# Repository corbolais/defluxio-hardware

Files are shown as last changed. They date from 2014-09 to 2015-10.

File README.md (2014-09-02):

Hardware for the netzsinus project
===================================

This repository contains the measurement hardware and firmware of the
netzsinus project. The current hardware is still under development -
you have to solder your own hardware. The hardware is, however, pretty
simple and easy to build.

Our vision is to develop a network analyzer in the sense of [DIN EN
50160](https://de.wikipedia.org/wiki/EN_50160). Currently, only the
network frequency is measured, but other measurements such as voltage
and harmonics will be included step-by-step.

Overview
--------

The hardware consists of

* A 9VAC wall-wart power adaptor. I have only tested Ideal Power model
DE-06-09, but others should also work.
* A STM32F4 Discovery board. This evaluation kit offers a Cortex M4
microcontroller which will become handy if we implement the harmonics
analysis.
* An adapter board which contains the analog frondend and connects all
the components.
* A raspberry pi which runs a simple Go daemon to read the data from the
hardware and transmit it to https://netzsin.us.

The current design powers the STM32F4 from the Raspberry Pi. It would also 
be possible to power the system from the 9VAC power adaptor, but initial 
experiments showed distorsions in the sine wave caused by the bridge rectifier.
A precision bridge rectifier setup could solve this.

Building your own device
------------------------

Currently, you just have to solder your own hardware. But since the
hardware is pretty simple this is an easy task. Please use this
schematic:

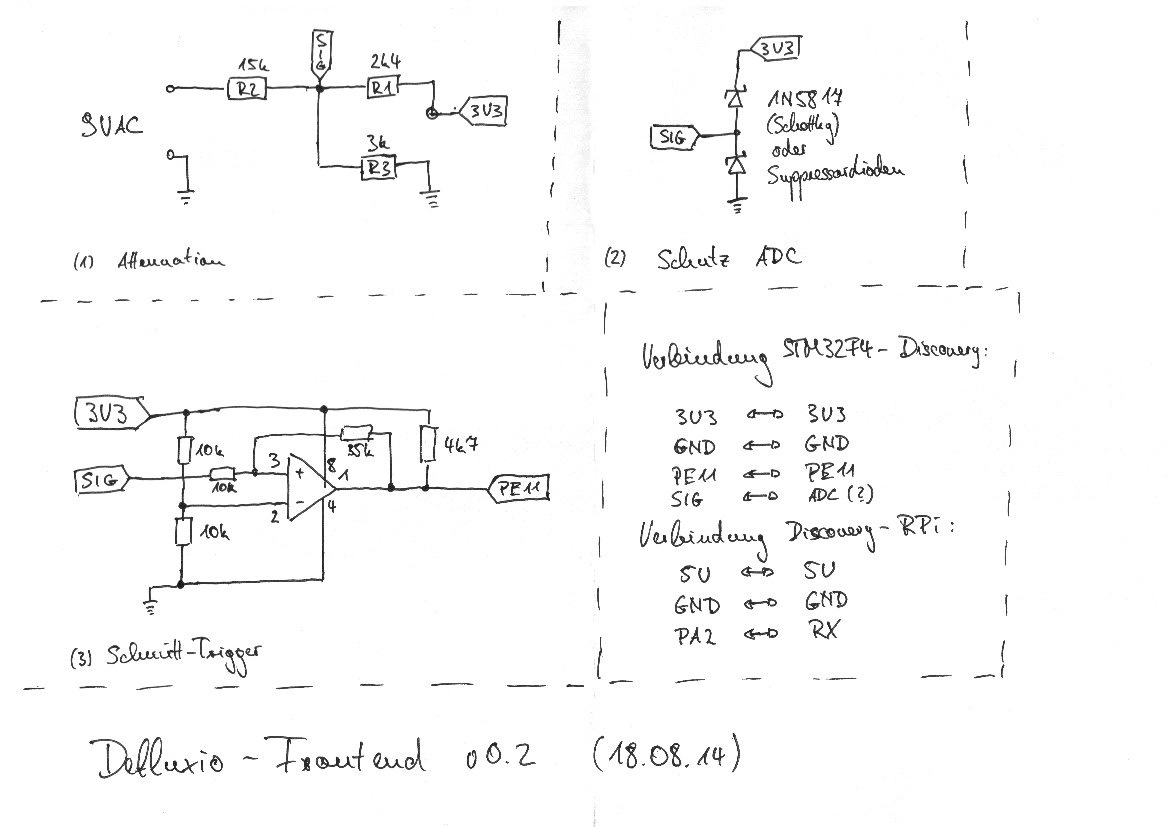
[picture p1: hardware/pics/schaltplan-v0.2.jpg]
Schematic


The opamp is an TLC393 comparator. I used a protoboard and THT components to build this circuit as a shield
for the STM32F4 discovery board. This is my setup:

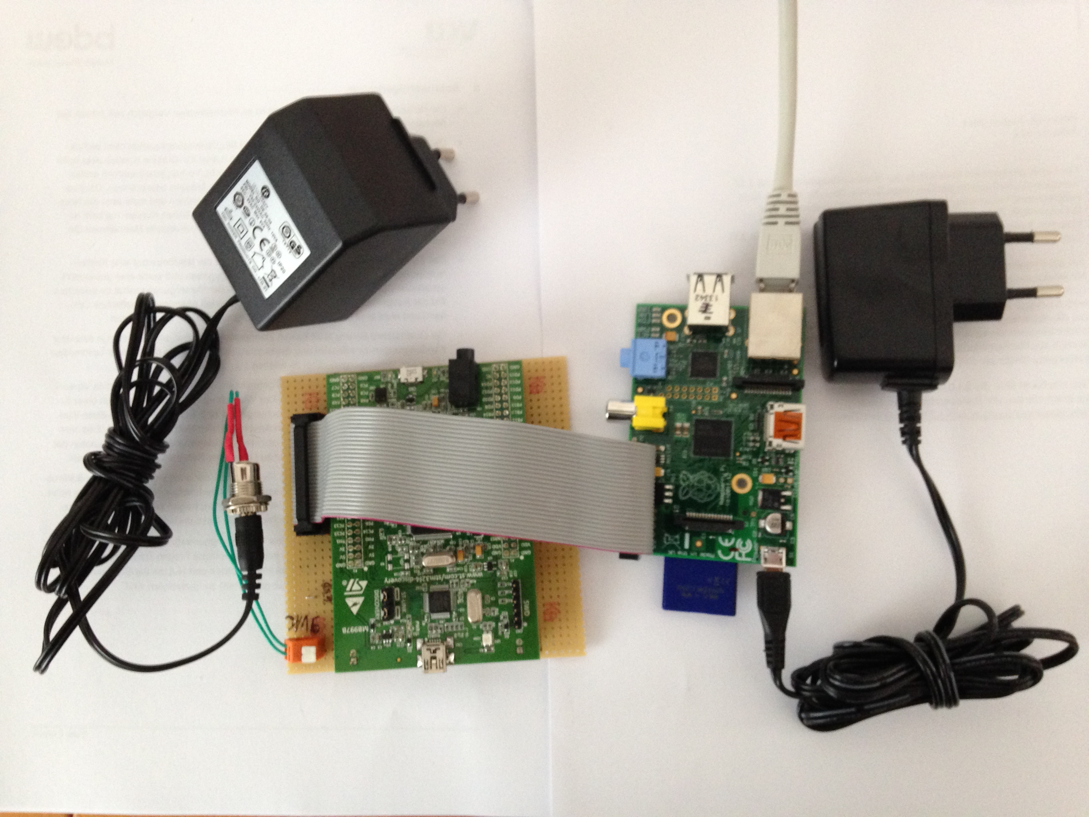
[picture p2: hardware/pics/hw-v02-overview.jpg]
Overview


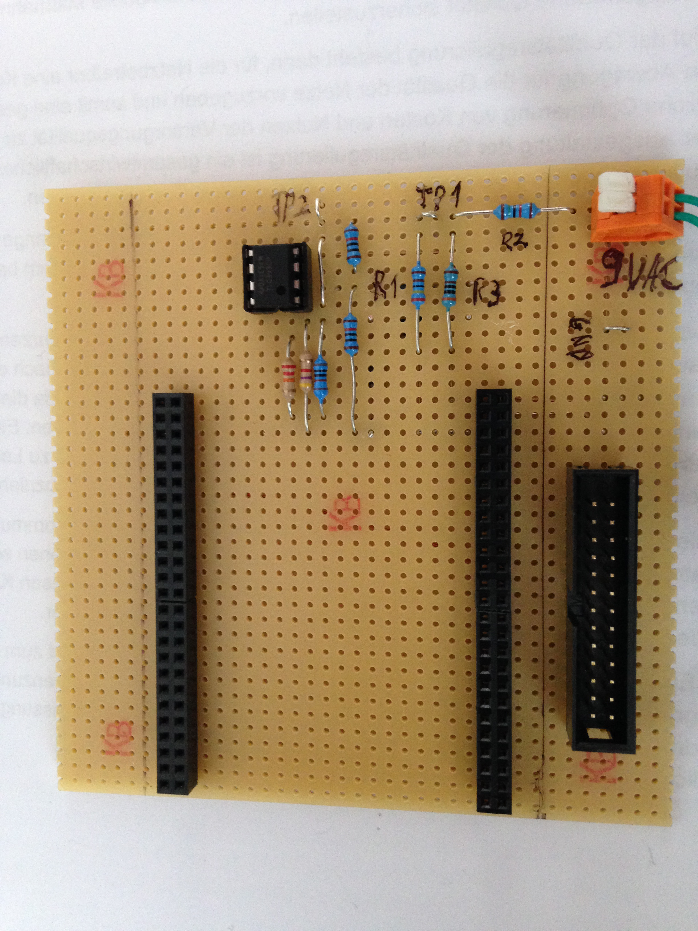
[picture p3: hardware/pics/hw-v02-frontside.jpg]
Front


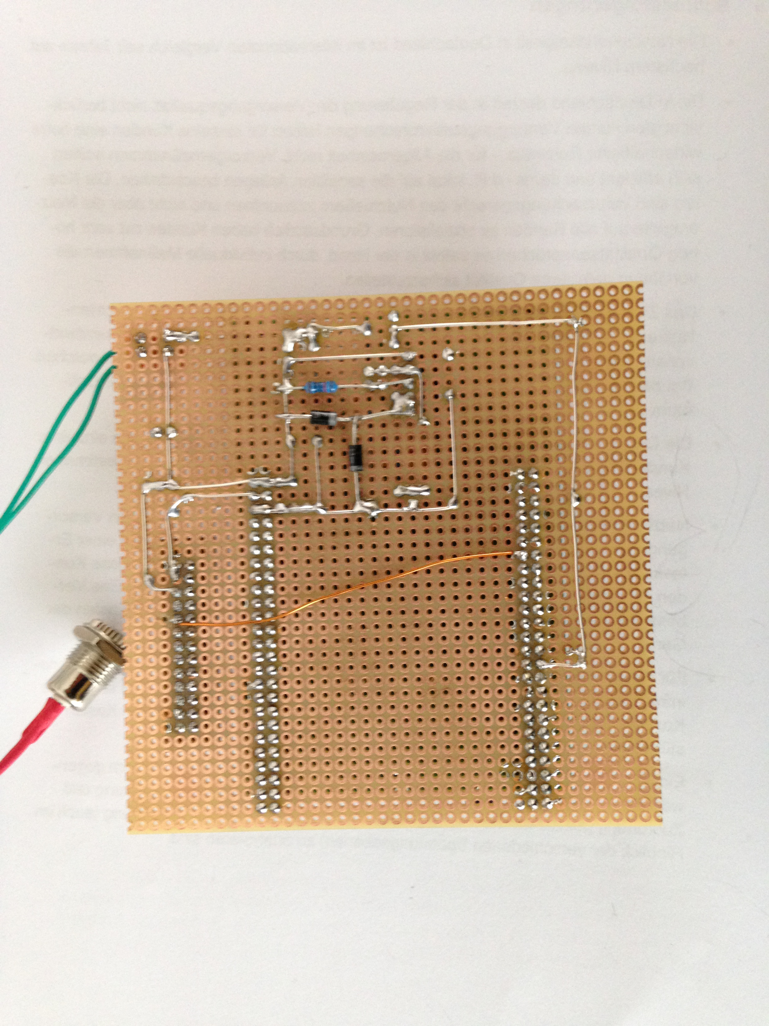
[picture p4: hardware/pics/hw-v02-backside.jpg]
Back


The STM32F4 discovery costs around 15 Euro, the 9VAC adaptor around 5,
everything else maybe 2 Euros.

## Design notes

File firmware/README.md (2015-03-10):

Netzsinus Firmware
==================

Prerequisites
-------------
The firmware has been successfully built on the following host systems:

* Ubuntu Linux 14.04
* Mac OS Mavericks

Please install the following prerequisites first:

* Install [gcc-arm-embedded](https://launchpad.net/gcc-arm-embedded) and
  make sure the arm-none-eabi-*-commands are in your path
* Install [OpenOCD](http://openocd.sourceforge.net/)

Then, clone the repository and change into the firmware subdirectory:

	$ cd defluxio-hardware/firmware

Building the firmware
---------------------

First, you need to grab and compile a copy of libopencm3:

	$ git submodule init
	$ git submodule update
	$ cd libopencm3
	$ make

This will compile the library. Afterwards, change into the src directory and
build the example:

	$ cd ../src
	$ make

Connect your STM32-Discovery board and run 

	$ make flash

to upload the binary into the microcontroller. In order to see the USART output,
connect a 3V3 TTL adaptor to PA2 (USART2_TX). You can use `screen` to see the output:

	$ screen /dev/ttyUSB0 115200

Please note: as of commit adc3d7d4, the firmware does only print an info
line when starting up. It will print frequency information only if a
plausible sine wave is detected, so please connect the AC adaptor. You
should see something similar to this:

````
I;Defluxio Frequency Measurement Hardware started.
I;Frequency: 50.022183 Hz, delta:  22 mHz
F;50.02218
I;Frequency: 50.018508 Hz, delta:  19 mHz
F;50.01851
I;Frequency: 50.016797 Hz, delta:  17 mHz
F;50.01680
I;Frequency: 50.015841 Hz, delta:  16 mHz
F;50.01584
I;Frequency: 50.016847 Hz, delta:  17 mHz
F;50.01685
````

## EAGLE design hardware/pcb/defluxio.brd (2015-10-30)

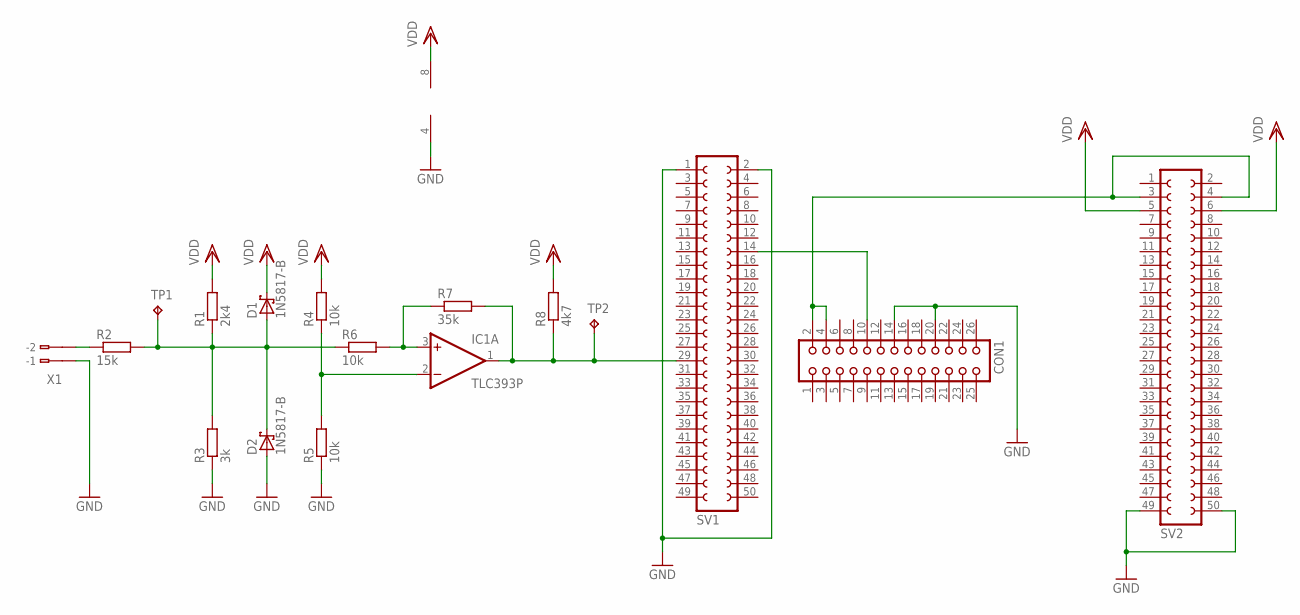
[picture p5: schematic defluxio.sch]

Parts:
CON1: CON26
D1, D2: 1N5817-B; DO41-7.6
IC1: TLC393P; DIL08
R1: 2k4; 0204/7
R2: 15k; 0207/12
R3: 3k; 0207/15
R4: 10k; 0207/12
R5: 10k; 0207/10
R6: 10k; 0204/7
R7: 35k; 0207/10
R8: 4k7; 0207/10
SV1, SV2: FE25-2
TP1, TP2: TPPAD1-13; P1-13
X1: 233-102

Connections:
5V: CON1.2, CON1.4, SV2.3, SV2.4
GND: CON1.14, CON1.20, D2.A, IC1.4 (V-), R3.1, R5.1, SV1.1, SV1.2, SV2.49, SV2.50, X1.B1 (B-1)
unnamed: R2.1, X1.B2 (B-2)
unnamed: IC1.3 (+IN), R6.2, R7.1
unnamed: IC1.2 (-IN), R4.1, R5.2
PE11: IC1.1 (OUT), R7.2, R8.1, SV1.29, TP2.TP
RX: CON1.10, SV1.14
SIG: D1.A, D2.C, R1.1, R2.2, R3.2, R6.1, TP1.TP
VDD: D1.C, IC1.8 (V+), R1.2, R4.2, R8.2, SV2.5, SV2.6

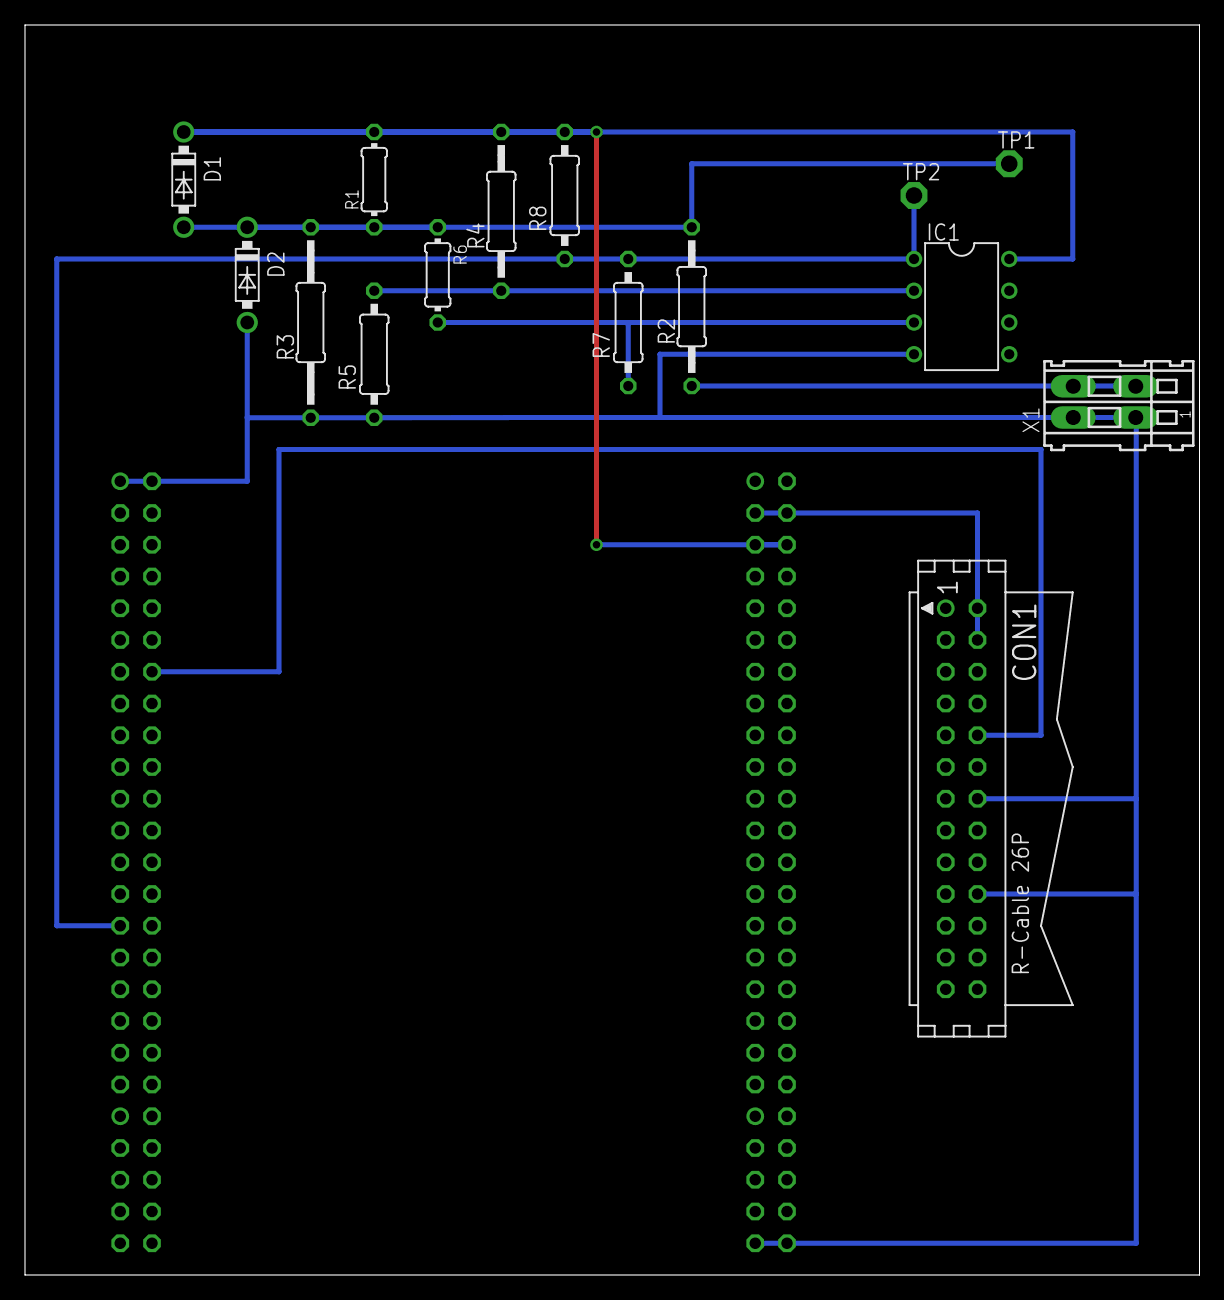
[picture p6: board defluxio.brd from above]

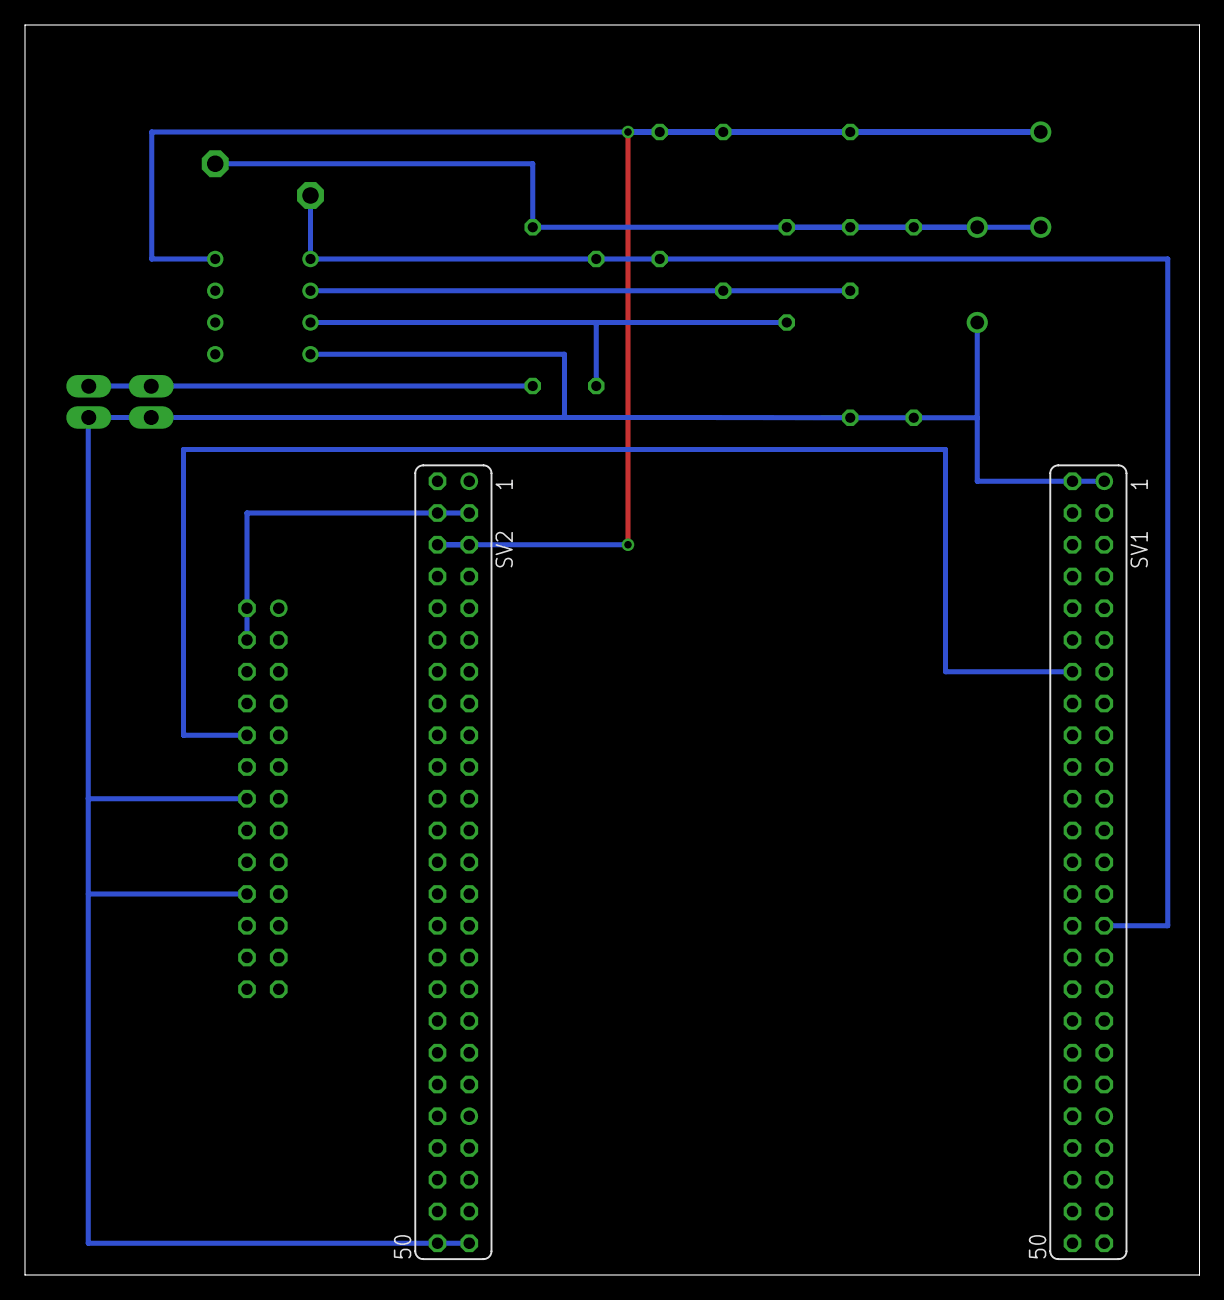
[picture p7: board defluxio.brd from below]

Board: 2 copper layers, 94.0 x 100.0 mm, 17 parts (2 on the bottom side), 9 nets.

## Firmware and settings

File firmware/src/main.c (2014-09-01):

/*
 * This file is part of the libopencm3 project.
 *
 * Copyright (C) 2009 Uwe Hermann <uwe@hermann-uwe.de>
 * Copyright (C) 2011 Stephen Caudle <scaudle@doceme.com>
 *
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
 * You should have received a copy of the GNU Lesser General Public License
 * along with this library.  If not, see <http://www.gnu.org/licenses/>.
 */


#include <stdio.h>
#include <stdlib.h>
#include <inttypes.h>
#include <libopencm3/stm32/rcc.h>
#include <libopencm3/stm32/gpio.h>
#include <libopencm3/stm32/usart.h>
#include "freq_capture.h"
#include "log_formatter.h"


static void clock_setup(void) {
  rcc_clock_setup_hse_3v3(&hse_8mhz_3v3[CLOCK_3V3_168MHZ]);
}


static void usart_setup(void) {
	/* Enable clocks for USART2 & GPIOA (TX pin). */
	rcc_periph_clock_enable(RCC_USART2);
	rcc_periph_clock_enable(RCC_GPIOA);
		/* Setup USART2 parameters. */
	usart_set_baudrate(USART2, 115200);
	usart_set_databits(USART2, 8);
	usart_set_stopbits(USART2, USART_STOPBITS_1);
	usart_set_mode(USART2, USART_MODE_TX);
	usart_set_parity(USART2, USART_PARITY_NONE);
	usart_set_flow_control(USART2, USART_FLOWCONTROL_NONE);
	/* Finally enable the USART. */
	usart_enable(USART2);
/* Setup GPIO pins for USART2 transmit. */
	gpio_mode_setup(GPIOA, GPIO_MODE_AF, GPIO_PUPD_NONE, GPIO2);
	/* Setup USART2 TX pin as alternate function. */
	gpio_set_af(GPIOA, GPIO_AF7, GPIO2);

}

static void led_setup(void) {
	/* Setup GPIO pin GPIO12 on GPIO port D for LED. */
	gpio_mode_setup(GPIOD, GPIO_MODE_OUTPUT, GPIO_PUPD_NONE, GPIO12);
	/* Enable GPIOD clock for LED. */
	rcc_periph_clock_enable(RCC_GPIOD);
}

int main(void) {
	clock_setup();
	usart_setup();
	led_setup();
	freq_capture_setup();
	log_info("Defluxio Frequency Measurement Hardware started.");
	char buf[100];
	while (1) {
		gpio_toggle(GPIOD, GPIO12);	/* LED as 'alive' signal*/
		freq_capture_start();
		while (freq_get_state() != IDLE) ;; /* wait for measurement to finish */
		double freq = freq_get_result();
		snprintf(buf, sizeof(buf), "Frequency: %f Hz, delta: %3.0f mHz", freq, (freq-50)*1000);
		log_info(buf);
		log_freq(freq);
	}
	return 0;
}

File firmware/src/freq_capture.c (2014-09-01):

#include "freq_capture.h"
#include <stdio.h>
#include <stdlib.h>
#include <inttypes.h>
#include <libopencm3/stm32/rcc.h>
#include <libopencm3/stm32/gpio.h>
#include <libopencm3/stm32/usart.h>
#include <libopencm3/stm32/timer.h>
#include <libopencm3/stm32/f4/nvic.h>


/* How many cycles do we use for a measurement? */
static const uint32_t NUM_EDGES = 50;
static const uint32_t TIMER1_HZ = 168000000;
static const uint32_t TIMER1_PERIOD = 0xFFFF;
static const uint32_t TIMER1_PRESCALER = 0xA8; // 1MHz sample rate

volatile mstate_t m_state = IDLE;
volatile uint32_t cycles_during_measurement = 0;
volatile uint32_t overcapture = 0;
volatile uint32_t overflow_counter = 0;
volatile uint32_t start_counter = 0;
volatile uint32_t edges = 0;


void freq_capture_setup(void) {
	/* Configure PE11 (AF1: TIM1_CH2) (SYNC_IN). */
	rcc_peripheral_enable_clock(&RCC_AHB1ENR, RCC_AHB1ENR_IOPEEN);
	gpio_mode_setup(GPIOE, GPIO_MODE_AF, GPIO_PUPD_NONE, GPIO11);
	gpio_set_af(GPIOE, GPIO_AF1, GPIO11);

	/* Timer1: Input compare */
	/* Enable timer clock. */
	rcc_peripheral_enable_clock(&RCC_APB2ENR, RCC_APB2ENR_TIM1EN);
	/* Reset timer. */
	timer_reset(TIM1);
	/* Configure timer1. */
	timer_set_mode(TIM1,
			TIM_CR1_CKD_CK_INT,		// Internal clock
			TIM_CR1_CMS_EDGE,			// Edge synchronization
			TIM_CR1_DIR_UP);			// Count upward
	timer_set_prescaler(TIM1, TIMER1_PRESCALER);
	timer_set_period(TIM1, TIMER1_PERIOD); //Sets TIM1_ARR
	timer_continuous_mode(TIM1);
	/* Configure PE13: Toggle pin on falling edge via interrupt */
	//rcc_peripheral_enable_clock(&RCC_AHB1ENR, RCC_AHB1ENR_IOPEEN);
	//gpio_mode_setup(GPIOE, GPIO_MODE_OUTPUT, GPIO_PUPD_PULLDOWN, GPIO13);
	/* Configure input capture. */
	timer_ic_disable(TIM1, TIM_IC2);
	timer_ic_set_polarity(TIM1, TIM_IC2, TIM_IC_RISING);
	timer_ic_set_prescaler(TIM1, TIM_IC2, TIM_IC_PSC_OFF);
	timer_ic_set_input(TIM1, TIM_IC2, TIM_IC_IN_TI2);
	// See RM, p. 561: digital filter
	//timer_ic_set_filter(TIM1, TIM_IC2, TIM_IC_DTF_DIV_32_N_8);
	timer_ic_set_filter(TIM1, TIM_IC2, TIM_IC_OFF);
	timer_ic_enable(TIM1, TIM_IC2);
	/* Enable counter. */
	timer_enable_counter(TIM1);
	timer_clear_flag (TIM1, TIM_SR_CC2IF);
	/* Enable IRQs */
	nvic_enable_irq(NVIC_TIM1_UP_TIM10_IRQ);
	timer_enable_irq(TIM1, TIM_DIER_UIE);
	nvic_enable_irq(NVIC_TIM1_CC_IRQ);
	timer_enable_irq(TIM1, TIM_DIER_CC2IE);
}


void tim1_up_tim10_isr(void) {
	if(timer_get_flag(TIM1, TIM_SR_UIF)) {
		timer_clear_flag(TIM1, TIM_SR_UIF);
		overflow_counter++;
	}
}


void tim1_cc_isr(void) {
	if(timer_get_flag(TIM1, TIM_SR_CC2IF)) {
		if (timer_get_flag(TIM1, TIM_SR_CC2OF)) 
			overcapture++;
		uint32_t current_counter = timer_get_counter(TIM1);
		uint32_t current_overflow = overflow_counter;
		timer_clear_flag(TIM1, TIM_SR_CC2IF);
		//gpio_toggle(GPIOE, GPIO13); /* toggle pin for 'scope debugging */
		if (m_state == PENDING) { // start measurement
			edges=0;
			start_counter = current_counter;
			overflow_counter = 0;
			m_state = RUNNING;
		}
		if (edges == NUM_EDGES) { // end measurement
			cycles_during_measurement = 
				(current_overflow*TIMER1_PERIOD) + current_counter - start_counter;
			m_state = IDLE;
		} else {
			edges += 1;
		}
	}
}

mstate_t freq_get_state(void) {
	return m_state;
}

void freq_capture_start(void) {
	m_state = PENDING; /* start new measurement */
}

double freq_get_result(void) {
	//printf("Cycles during measurement: %" PRId32 ", no. of overflows: %" PRId32 ", overcapture: %" PRId32"\n", cycles_during_measurement, overflow_counter, overcapture);
	double avg_period = (double) cycles_during_measurement /
		(((double) TIMER1_HZ / (double) (TIMER1_PRESCALER+1)) * edges);
//	printf("Period: %1.6f, Frequency: %f, delta %3.0f mHz\n", avg_period, 1/(avg_period), (1/(avg_period)-50)*1000);
	return 1/avg_period;
}

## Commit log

2014-08-19 input capture infrastructure is working, but overflow handling is broken.
    [main.c]
2014-09-02 power design background
2015-10-30 added EAGLE PCB (first draft) from schematics in pics directory
    [defluxio.brd, defluxio.sch]

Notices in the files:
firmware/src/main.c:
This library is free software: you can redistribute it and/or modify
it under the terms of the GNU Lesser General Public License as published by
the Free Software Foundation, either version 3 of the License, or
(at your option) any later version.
